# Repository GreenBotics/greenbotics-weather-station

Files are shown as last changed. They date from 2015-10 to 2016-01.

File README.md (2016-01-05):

# GreenSkies

> Open source, somewhat low cost Weather station project

## Infos so far:

- temperature, humidity, barometric pressure sensor : BME180 
- anemometer (wind speed) hall effect sensor

- remote  but not too much (garden based) : using a ESP8266 as "brain" + network
- low power as much as possible + solar powered if possible

## various thoughts on UI:

Needs:
- access to multiple "nodes"/locations
- zoom/pan for longer data series
- possibility to split & merge data from different sensors & location (for cross
referencing "events" at a given time, across sensors)

## Cad

Using OpenJSCad + Es6 + Ramda 

very roughly it uses browserify + babel 

  ```npm run watch```

then drag & drop cad/out/index.jscad.js into openjscad

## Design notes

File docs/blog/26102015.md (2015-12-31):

26/10/2015
==========

Lots of new things learned tonight:

- how "percieved"/feels like temperature is computed: https://en.wikipedia.org/wiki/Heat_index
- what EC (Electro condictivity) of liquids for hydro/aquaponics is used for 

I was also , yet again, taking a look at dissolved oxygen & ph **sensors** , and still in shock at their very high price, 
and "fragility" (they have to be recalibrated regularly etc): these sensors are 3 orders of magnitude above the cost of 
temperature/pressure/humidity sensors, but they are **very** important to ensure a reliable, scientific method of
growing plants ...

There are not many ways (if at all) to create these sensors in a DIY manner. 
Somedays, I *really* wish I was either a physicist, a chemist , or both.

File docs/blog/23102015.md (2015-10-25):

23/10/2015
==========

No so much progress in the past few days: 
- simply wired up an other ESP8266 + BME280 combo to act as a second , 
simpler, in door node (likely close by to my existing indoor
aquaponics setup, just to reuse the already running Arduino/replace it).

Really need to pick up speed, still hope to get the WHOLE project finished within a month.

Some more thoughts on software architecture:

- going to favor "simple, clunky & unfancy, but it just works" over some more complex, "elegant"
solutions , this means going for the simplest solutions: for example, I'll just keep seperate
Arduino sketches for the different nodes (which have different sensors, different static ips etc) 
instead of a super dynamic system that can handle different sensors with software toggles etc

Refactoring can come later, and only if the rest works.

Now will I be able to keep things simple for the UI too and not waste time on it ? I better make sure.

- the "hub"'s server should be the one communicating with the different nodes,
not the client directly: this reduces risk of client brining down the sensor nodes
also if the hub is the one who will store the data / aggregate it makes things easier

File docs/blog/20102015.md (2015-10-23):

20/10/2015
==========

Hardware:
---------

Managed to get Olimex MOD-WIFI-ESP8266 working!

Things were not as trivial as hoped initially :
 * unlike what the official document says , it is possible to reflash the firmware
 by setting pins 21 LOW and pulsing pin 13 LOW , (or more simply, add two buttons to do it )
 * for some reason, I fried my first FTDI programmer (FTDI basic) on the first try 
 * I'll try and add a wiring schematic here

 Another few things worth noting:
  * the board seems to be much more stable then the Adafruit Huzzah (no weird resets/continuous reboots)
  * so stable in fact that it has been running almost non stop since without much of a hiccup
  * the 3.3v power is supplied by an older Arduino Due and seems fine for my use case

Software:
---------

More progress on the Cycle.js based UI (still need to regroup all of it here)
 * solved issues with Graphing
 * better data handling

Infrastructure and decisions
----------------------------

Storage:
--------

Not sure how to deal with data storage just yet .
Garden weather station would be maximum 10 -15 meters from indoors (and router)...So a fully autonomous station 
might not be needed

Here are a few options 
* sd card directly with the weather station: "simple", perhaps lower power
* raspberry-pi (or similar) acting as a "central hub": this would make it easier to handle multiple "sensor nodes"
(minimal indoor temperature & humidity sensing). This does not entirely solve the storage question, but there are more possibilities.

Power:
------

Needs to be solar for the outside weather station (not quite enough wind in the area), want to avoid complex wiring from within the house.

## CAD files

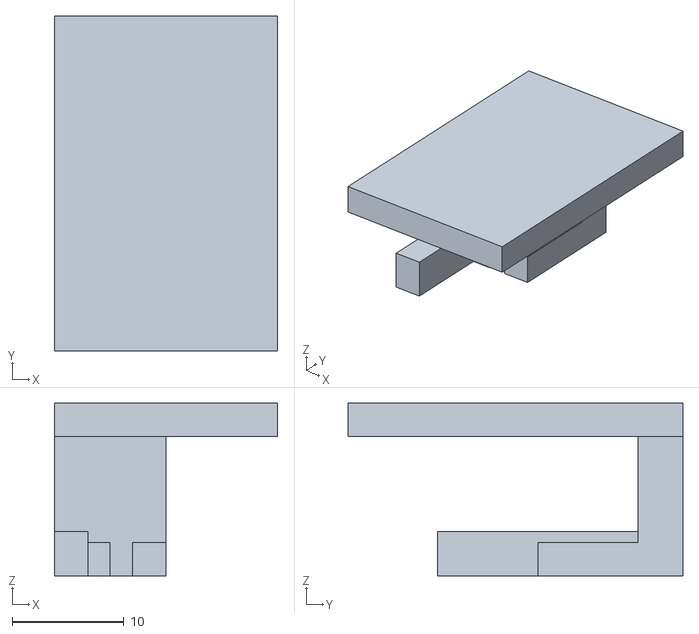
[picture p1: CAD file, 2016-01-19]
cad/bin/slideDoorHolder_frontArm.stl
20.0 x 30.0 x 15.5

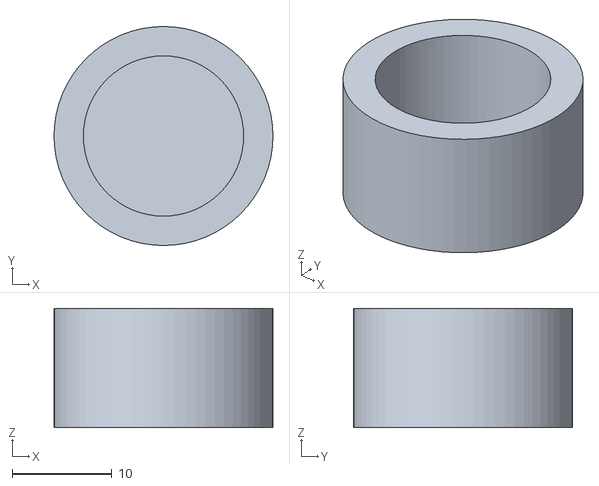
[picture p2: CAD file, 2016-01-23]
cad/src/Yatoopi/tubeCap.stl
22.0 x 22.0 x 12.0

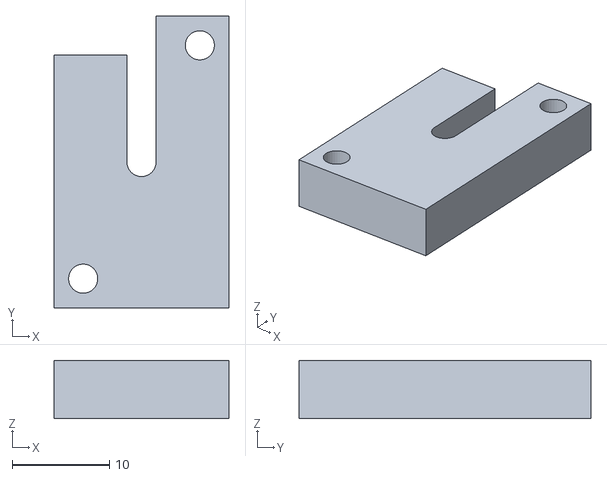
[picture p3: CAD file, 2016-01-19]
cad/bin/slideDoorHolder_mountBlock.stl
18.0 x 30.0 x 6.00

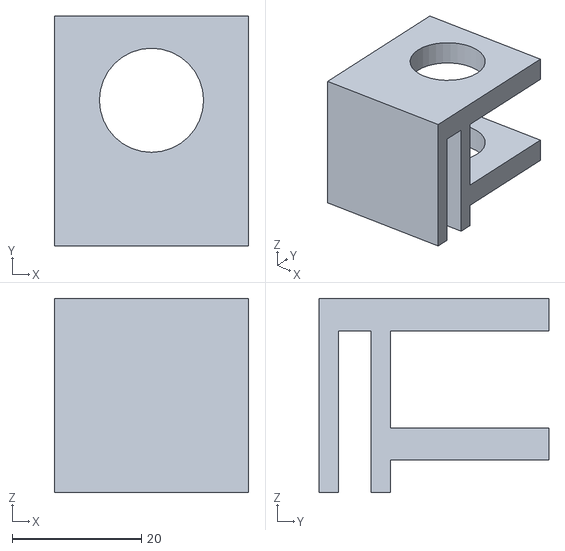
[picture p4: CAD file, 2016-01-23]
cad/src/Yatoopi/aquariumEdgeTubingHolder.stl
30.0 x 35.5 x 30.0

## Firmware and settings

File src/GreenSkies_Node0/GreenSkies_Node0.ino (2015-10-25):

#include <ESP8266WiFi.h>
#include <aREST.h>
#include <EEPROM.h>

#include <Wire.h>
#include <SPI.h>
#include <Adafruit_Sensor.h>
#include <Adafruit_BME280.h>
#include <Adafruit_SI1145.h>

#include "configuration.h"
#include "getUserInput.h"
#include "sensors.h"

// Create aREST instance
aREST rest = aREST();
//BME280 instance 
Adafruit_BME280 bme; // I2C
Adafruit_SI1145 uv = Adafruit_SI1145();//I2C too
//RPMMeasurer windRpm;

// WiFi parameters
bool wifiInitStarted = true;
bool wifiInitDone    = false;
bool ssidInitialized = false;
bool passwordInitialized = false;

// Create an instance of the server
WiFiServer server(LISTEN_PORT);

// Variables to be exposed to the API
float temperature;
float humidity;
float pressure;
float windSpd;
float windDir;
float rain;
float visL;
float irL;
float UVL; 

///for wind speed
int hallPin = 12;
float windRPM;
int curState = 1;
int prevState = 1;
int rInCycle = 1;

unsigned long startTime;
unsigned long currentTime;
unsigned long elapsedTime; 

void setup(void)
{  
  // Start Serial
  Serial.begin(115200);
  //configure I2C
  Wire.pins(13,14);


  pinMode(hallPin, INPUT);
  
  // Init variables and expose them to REST API
  temperature = 0;
  humidity = 0;
  pressure = 0;
  windSpd  = 0;
  windDir  = 0;
  rain     = 0;
  visL     = 0;
  irL      = 0;
  UVL      = 0;

  rest.variable("temperature",&temperature);
  rest.variable("humidity",&humidity);
  rest.variable("pressure",&pressure);
  rest.variable("rain",&rain);
  rest.variable("windSpd",&windSpd);
  rest.variable("windDir",&windDir);
  rest.variable("visL",&visL);
  rest.variable("irL",&irL);
  rest.variable("UVL",&UVL);
  
  // Give name and ID to device
  rest.set_id("0");
  rest.set_name("GreenSkies_Node0");

  while( !bme.begin() ) {
    Serial.println("Could not find a valid BME280 sensor, check wiring!");
    myDelay(1000);
  }

  while( !uv.begin() ) {
    Serial.println("Didn't find Si1145");
    myDelay(1000);
  }

}



void setupWifi(){
  // Connect to WiFi
  WiFi.begin( ssid, password );
  //set static ip part
  WiFi.config(ip, gateway, subnet);
  
  while (WiFi.status() != WL_CONNECTED) {
    myDelay(500);
    Serial.print(".");
  }
  Serial.println("");
  Serial.println("WiFi connected");
 
  // Start the server
  server.begin();
  Serial.println("Server started");
  
  // Print the IP address
  Serial.print(WiFi.localIP());
  Serial.print(":");
  Serial.print(LISTEN_PORT);
  Serial.println();
}

void handleRestCalls(){
  // Handle REST calls
  WiFiClient client = server.available();
  if (!client) {
    return;
  }
  while(!client.available()){
    myDelay(1);
  }
  rest.handle(client);
}


//////////////////
void loop() {
  myDelay(1);
  if(wifiInitStarted && ! wifiInitDone){
    setupWifi();
    wifiInitDone = true;
  }
  if(wifiInitDone){
    handleRestCalls();
  }

  //fetch sensor data
  temperature = bme.readTemperature();
  pressure    = bme.readPressure() / 100.0F;
  humidity    = bme.readHumidity();

  visL        = uv.readVisible();
  UVL         = uv.readIR();
  irL         = uv.readUV();

  //windSpd     = measureRpm();
  measureRpm();
}

float measureRpm() 
{ 
  
  curState = digitalRead(hallPin);
  int pulses_per_rev = 1;

  currentTime = millis();
  elapsedTime = currentTime - startTime;
   
  if(curState == 0 && prevState != curState){
    
    float rpm = 60000/(elapsedTime*pulses_per_rev);

    //reset
    startTime = millis();
    prevState = curState;
    //if(rpm != windRPM)
    //{
      windSpd = rpm;
      windRPM = rpm;
    //}
    //Serial.print("windSpd");
    //Serial.println(rpm);
  }
  /*else if(elapsedTime >= 60000){//more than a minute without activity, reset
    windSpd = 0;
  }*/
  
  prevState = curState;

}


void myDelay(int ms) {
    int i;
    for(i=1;i!=ms;i++) {
          delay(1);
          if(i%100 == 0) {
                  ESP.wdtFeed(); 
                  yield();
          }
    }
}

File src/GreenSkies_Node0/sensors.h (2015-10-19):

/*
#include <Wire.h>
#include <SPI.h>
#include <Adafruit_Sensor.h>
#include <Adafruit_BME280.h>

#define BME_SCK 13
#define BME_MISO 12
#define BME_MOSI 11
#define BME_CS 10

#define SEALEVELPRESSURE_HPA (1013.25)

Adafruit_BME280 bme; // I2C */


struct RPMMeasurer {
  int hallPin;
  int windRPM;
  int curState;
  int prevState;
  
  unsigned long startTime;
  unsigned long currentTime;
  unsigned long elapsedTime; 

  RPMMeasurer(){
    windRPM = 0;
    curState = 0;
    prevState= 0;
  
    startTime = millis();
    currentTime = millis();
    elapsedTime = 0; 

    hallPin = -1;
  }

  RPMMeasurer(int hallPin){
    windRPM = 0;
    curState = 0;
    prevState= 0;
  
    startTime = millis();
    currentTime = millis();
    elapsedTime = 0; 

    hallPin = hallPin;
    setup();
  }

  void setup(){
    pinMode(hallPin, INPUT);
  }
  
  int measure() 
  { 
    
    curState = digitalRead(hallPin);
    int time_between_pulses = 10;
    int pulses_per_rev = 1;
    
    if(curState != prevState){
      currentTime = millis();
      elapsedTime = currentTime - startTime;
      windRPM = 60000/(elapsedTime*pulses_per_rev);

      //reset
      prevState = curState;
      startTime = millis();
      currentTime = millis();
      
      return curState;
    }
  }
};


/*const int hallPin = 2; 
const int ledPin =  0;    
int hallState = 0; 

RPMMeasurer rpm;


void setup() {
  pinMode(ledPin, OUTPUT);
  pinMode(hallPin, INPUT);
  
  Serial.begin(115200);
  Serial.println(F("BME280 test"));

  if (!bme.begin()) {
    Serial.println("Could not find a valid BME280 sensor, check wiring!");
    while (1);
    delay(1000);
  }
}



void loop() {
    hallState = digitalRead(hallPin);
    rpm.measure(hallState);
    
    Serial.print("Temperature = ");
    Serial.print(bme.readTemperature());
    Serial.println(" *C");

    Serial.print("Pressure = ");

    Serial.print(bme.readPressure() / 100.0F);
    Serial.println(" hPa");

    Serial.print("Approx. Altitude = ");
    Serial.print(bme.readAltitude(SEALEVELPRESSURE_HPA));
    Serial.println(" m");

    Serial.print("Humidity = ");
    Serial.print(bme.readHumidity());
    Serial.println(" %");

    Serial.print("Hall sensor state = ");
    Serial.println(hallState);
    
    Serial.println();
    delay(2000);
}*/

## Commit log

2015-10-17 refactor(): moved user input getting into a different module - also started adding (back) sensor data fetching
2015-10-17 feature(): arduino firmware is correctly returning sensor data from BME280 via rest api / json ! yeah !
    [GreenSkies.ino, sensors.h]
2015-10-19 feature(sensors): fleshed out different sensors: - added light sensor "feed" - experimenting with wind speed measurement
2015-10-20 various(): added workarounds to prevent bad reseting of the esp8266 board - temporarly stripped out the manually entering of wifi settings for easier testing - added working wind speed/ rpm measureme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
    [GreenSkies.ino]
2015-10-25 feature(multipleNodes): split out "firmware" code into two seperate Arduino sketches - cleaned up code of both nodes' firmware - refactored accordingly
    [configuration.h]
2015-12-31 feature(cad): started basics of cad files: this time , another attempt at using openjscad, in a more functional manner: - added package, babelrc and some build helpers (es6) - added basics of wind va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
2016-01-01 refactor(cad): - split out various parts into seperate modules - added helpers (wrappers) to automatically deal with arrays / observables (wrapping original constructs) , also allows more readeable f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
2016-01-03 feature(wrapper): - added curried translate rotate, mirror functions - added wrapped chain_hull - cleaned up and reorganized wrappers slightly
2016-01-05 chore(README): - added basic infos about cad workflow to readme
2016-01-18 feature(weatherStation): - updated and continued fleshing out various pieces of the weather station cad files
2016-01-19 binaries(slideDoorHolder): - added missing stl files for sliding door holder parts
    [slideDoorHolder_frontArm.stl, slideDoorHolder_mountBlock.stl]
2016-01-23 features(yatoopi): - moved doorHolder to yatoopi folder (before repo change) - created aquariumEdgeTubingHolder - created tubeCap
    [aquariumEdgeTubingHolder.stl, tubeCap.stl]
